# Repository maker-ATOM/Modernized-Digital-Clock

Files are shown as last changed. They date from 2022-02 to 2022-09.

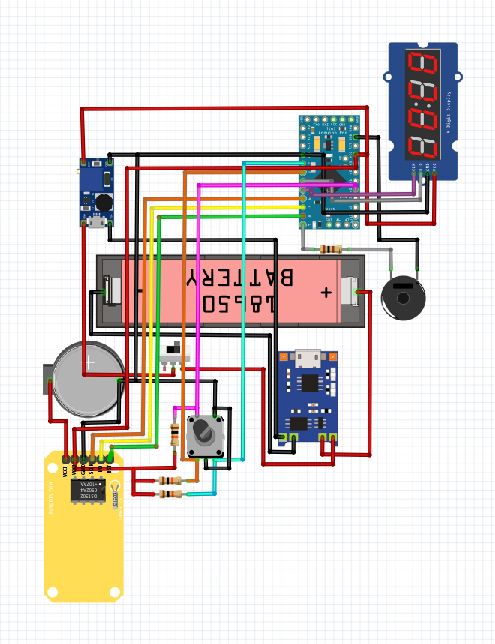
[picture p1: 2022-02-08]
Schematics/fritzing_schematic.jpg

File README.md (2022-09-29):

# Modernized-Digital-Clock
Build Instructions: https://www.instructables.com/Modernized-Digital-Clock/



### Rendered Image

FAG5CKHKYLK3PZ0

### Exploded view

exploded

Usage Guide of the clock: https://youtu.be/vWBFiRBEp3g

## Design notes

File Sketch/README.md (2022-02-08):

Arduino programs files to program the clock.

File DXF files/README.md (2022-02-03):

DXF file to laser cut the acrylic sheet.
Acrylic sheet 3mm thick clear black. Allows only limited light to pass thorugh without dispersing the light and retains the shape of object.

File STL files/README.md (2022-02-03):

STL files to 3D print.
3D printed in PLA GREY with 0.4mm nozzle, 0.2mm layer height and 100% infill.

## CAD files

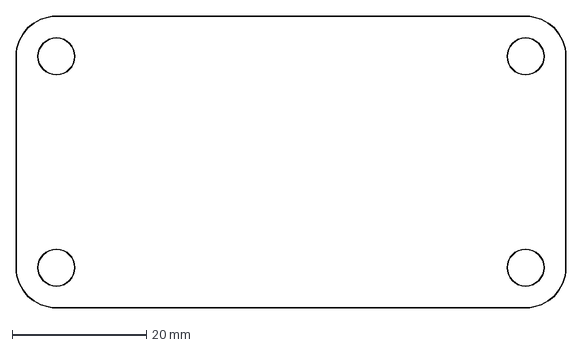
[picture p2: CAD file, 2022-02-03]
DXF files/face plate.dxf
82.0 x 43.5 mm

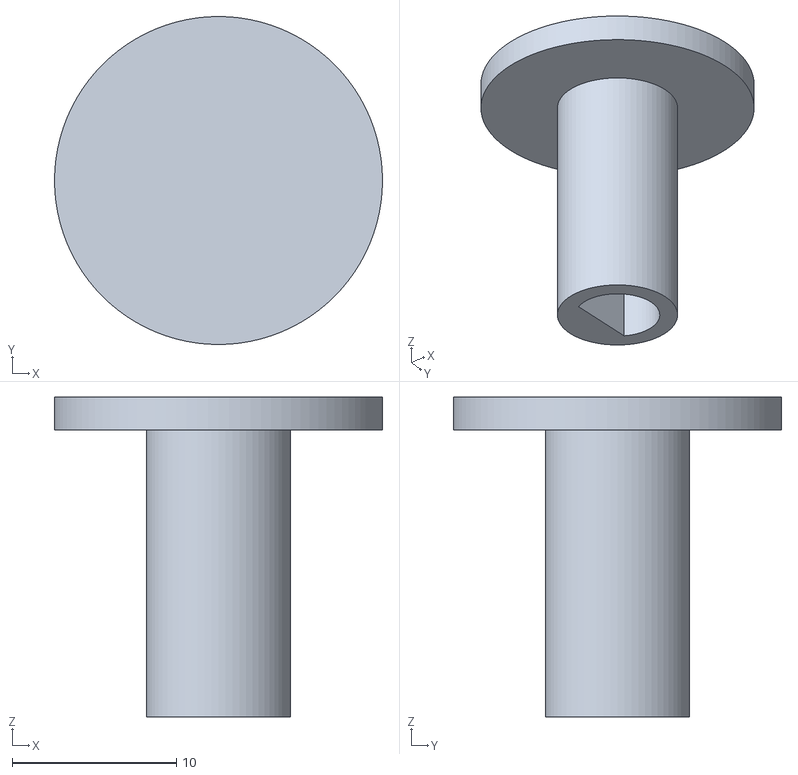
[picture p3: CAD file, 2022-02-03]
STL files/knob.stl
20.0 x 20.0 x 19.5

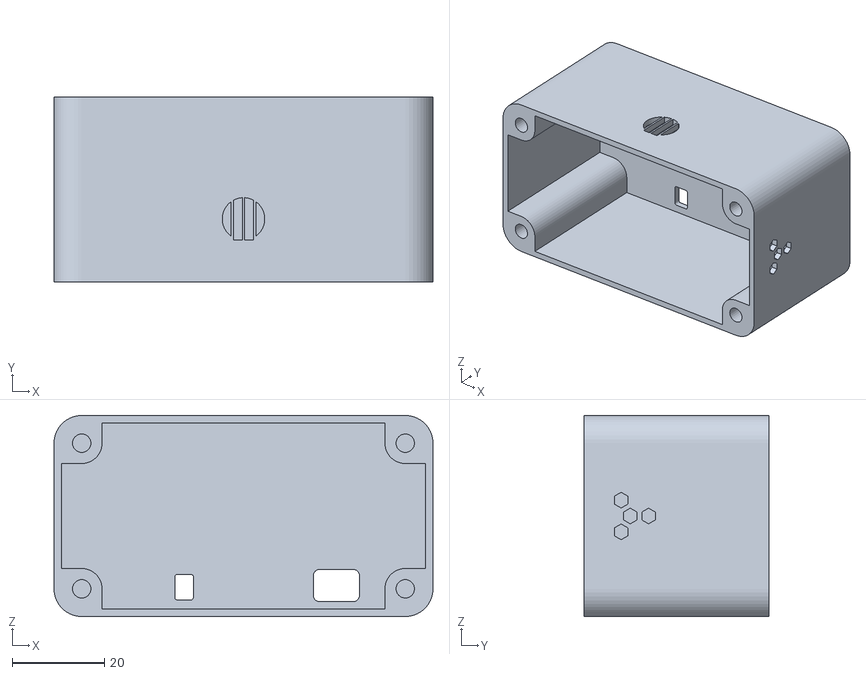
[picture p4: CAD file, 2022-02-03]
STL files/body.stl
82.0 x 40.0 x 43.5

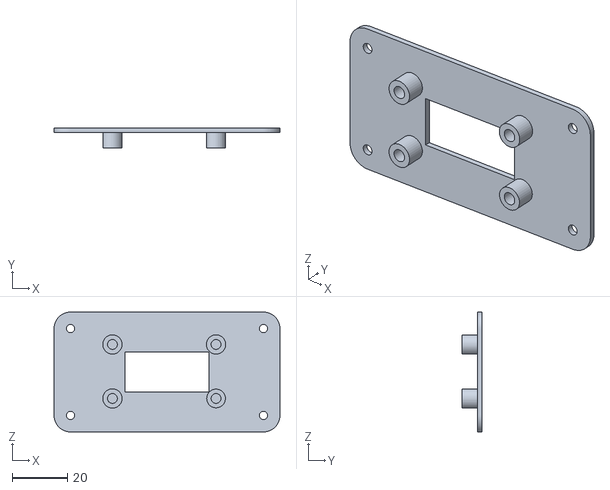
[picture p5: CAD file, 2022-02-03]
STL files/back plate.stl
82.0 x 7.20 x 43.5

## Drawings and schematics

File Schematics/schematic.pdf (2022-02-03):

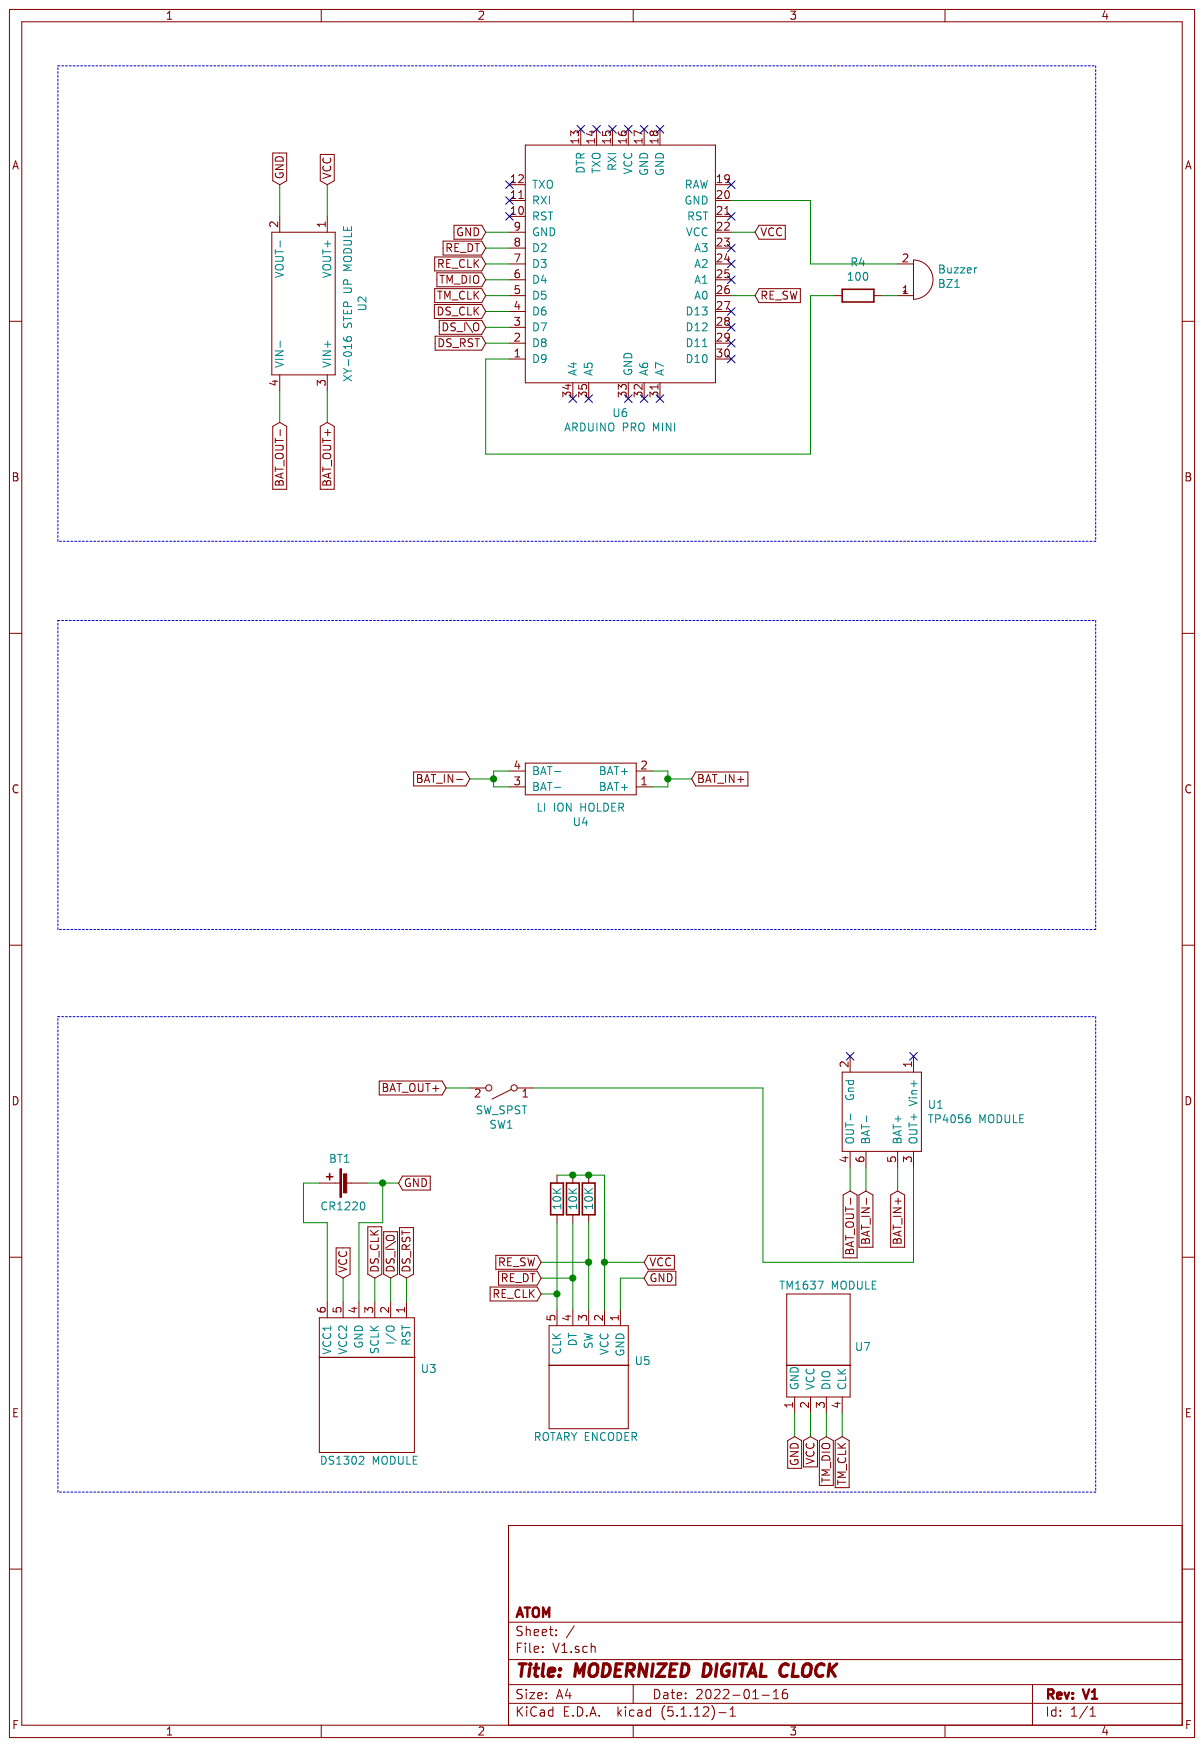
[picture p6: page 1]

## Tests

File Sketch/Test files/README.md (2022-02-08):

These programs are for debugging particularly to check which module is not working properly if any.

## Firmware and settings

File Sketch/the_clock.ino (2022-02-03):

//libraries
#include <TM1637Display.h>
#include <DS1302.h>

//macros
#define TM_CLK 5
#define TM_DIO 4

#define RE_CLK 3
#define RE_DT 2

#define RTC_CLK 6
#define RTC_DIO 7
#define RTC_CE 8

#define buzzer 9

//varibles
volatile byte nowRE_DT = 1;
volatile byte prevRE_DT = 1;

volatile byte button = 0;
byte buttonPressed = false;

volatile byte counter = 0;
byte prevcounter = 0;

byte td1 = 0, td2 = 0, td3 = 0, td4 = 0;
byte ad1 = 0, ad2 = 0, ad3 = 0, ad4 = 0;

byte digichange = 0;
int gettime = 0;

byte brightness = 4;

int setalarm = 0;
byte alarmFlag = false;

//array to display words
uint8_t full[] = {0xff, 0x0ff, 0xff, 0xff};
uint8_t blank[] = {0x00, 0x00, 0x00, 0x00};
uint8_t bright[] = {0x7c, 0xd0, 0x6f, 0x31};
uint8_t set[] = {0x6d, 0x79, 0x31, 0x00};
uint8_t timearr[] = {0x31, 0x30, 0x52, 0x79};
uint8_t dipy[] = {0x5e, 0x30, 0x73, 0x66};
uint8_t alarm[] = {0x77, 0x38, 0x50, 0x52};
uint8_t on[] = {0x00, 0x3f, 0x54, 0x00};
uint8_t off[] = {0x3f, 0x71, 0x71, 0x00};

TM1637Display display = TM1637Display(TM_CLK, TM_DIO);

DS1302 rtc(RTC_CE, RTC_DIO, RTC_CLK);

Time t;

//---------------------------------------------------------------------------------//

void setup()
{
  //register maipulation to set pin change interrupt on A0 pin
  PCICR |= B00000010;
  PCMSK1 |= B00000001;

  pinMode(RE_CLK, INPUT);
  pinMode(RE_DT, INPUT);

  //set the pin to high impedance so humming is inherted
  pinMode(buzzer, INPUT);

  attachInterrupt(digitalPinToInterrupt(2), updateEncoder, CHANGE);
  attachInterrupt(digitalPinToInterrupt(3), updateEncoder, CHANGE);

  display.setBrightness(brightness);

  rtc.halt(false);
  rtc.writeProtect(false);
}

//---------------------------------------------------------------------------------//

void loop()
{

  switch (button)
  {

    case 1: //show time
      display.setSegments(dipy);
      delay(1500);
      display.setSegments(timearr);
      delay(1500);
      while (!buttonPressed)
      {
        t = rtc.getTime();
        gettime = t.min;
        gettime = gettime + (t.hour * 100);
        display.showNumberDecEx(gettime, B01000000, true, 4, 0);

        if ((setalarm == gettime) && (alarmFlag))
        {
          prevcounter = counter;
          while (prevcounter == counter)
          {
            alarmSound();
          }
          alarmFlag = false;
          buttonPressed = false;
        }
        delay(2000);
      }
      break;



    case 2: //change time
      beep();
      display.setSegments(set);
      delay(1500);
      display.setSegments(timearr);
      delay(1500);
      while (!buttonPressed)
      {
        buttonPressed = false;
        if (counter != prevcounter)
        {
          display.setSegments(blank);
          if (counter > prevcounter)
          {
            digichange = (digichange + 1) % 4;
          }
          else
          {
            switch (digichange)
            {
              case 0:
                td4 = (td4 + 1) % 10;
                break;
              case 1:
                td3 = (td3 + 1) % 10;
                break;
              case 2:
                td2 = (td2 + 1) % 10;
                break;
              case 3:
                td1 = (td1 + 1) % 10;
                break;
            }
            rtc.setTime(td4 * 10 + td3, td2 * 10 + td1, 00);
          }
          switch (digichange)
          {
            case 0:
              display.showNumberDec(td4, false, 1, 0);
              break;
            case 1:
              display.showNumberDec(td3, false, 1, 1);
              break;
            case 2:
              display.showNumberDec(td2, false, 1, 2);
              break;
            case 3:
              display.showNumberDec(td1, false, 1, 3);
              break;
          }
          beep();
          prevcounter = counter;
        }
        delay(5);
      }
      break;

    case 3: //change brightness
      beep();
      display.setSegments(set);
      delay(1500);
      display.setSegments(bright);
      delay(1500);
      while (!buttonPressed)
      {
        buttonPressed = false;
        display.setSegments(full);
        if (counter != prevcounter)
        {
          if (brightness > 7)
          {
            brightness = 0;
          }
          brightness++;
          display.setBrightness(brightness);
          prevcounter = counter;
          beep();
        }
        delay(5);
      }
      break;

    case 4: //set alarm
      beep();
      display.setSegments(set);
      delay(1500);
      display.setSegments(alarm);
      delay(1500);
      while (!buttonPressed)
      {

        if (counter != prevcounter)
        {

          alarmFlag = !alarmFlag;
          if (alarmFlag)
          {
            display.setSegments(on);
            beep();
            delay(2000);
            while (!buttonPressed)
            {
              if (counter != prevcounter)
              {
                beep();
                display.setSegments(blank);
                if (counter > prevcounter)
                {
                  digichange = (digichange + 1) % 4;
                }
                else
                {
                  switch (digichange)
                  {
                    case 0:
                      ad4 = (ad4 + 1) % 10;
                      break;
                    case 1:
                      ad3 = (ad3 + 1) % 10;
                      break;
                    case 2:
                      ad2 = (ad2 + 1) % 10;
                      break;
                    case 3:
                      ad1 = (ad1 + 1) % 10;
                      break;
                  }
                  setalarm = (ad4 * 1000) + (ad3 * 100) + (ad2 * 10) + ad1;
                }
                switch (digichange)
                {
                  case 0:
                    display.showNumberDec(ad4, false, 1, 0);
                    break;
                  case 1:
                    display.showNumberDec(ad3, false, 1, 1);
                    break;
                  case 2:
                    display.showNumberDec(ad2, false, 1, 2);
                    break;
                  case 3:
                    display.showNumberDec(ad1, false, 1, 3);
                    break;
                }

                prevcounter = counter;
              }
              delay(5);
            }

          }
          else
          {
            display.setSegments(off);
          }
          prevcounter = counter;
          beep();
        }
        delay(5);
      }
      break;
    default:
      button = 1;
  }

  buttonPressed = false;

}

//---------------------------------------------------------------------------------//

ISR (PCINT1_vect)
{
  if (!digitalRead(A0))
  {
    button++;
    buttonPressed = true;
  }
  delay(1);
}

//---------------------------------------------------------------------------------//

void updateEncoder()
{
  nowRE_DT = digitalRead(3);
  if ((nowRE_DT != prevRE_DT) && digitalRead(2))
  {
    if (nowRE_DT)
    {
      counter--;
    }
    else
    {
      counter++;
    }
  }
  prevRE_DT = nowRE_DT;
}

//---------------------------------------------------------------------------------//

void beep()
{
  tone(buzzer, 1500);
  delay(50);
  noTone(buzzer);
  pinMode(buzzer, INPUT);
}

//---------------------------------------------------------------------------------//

void alarmSound()
{
  tone(buzzer , 1000);
  delay(200);
  noTone(buzzer);
  tone(buzzer, 1000);
  delay(200);
  noTone(buzzer);
  delay(1250);
}

//---------------------------------------------------------------------------------//

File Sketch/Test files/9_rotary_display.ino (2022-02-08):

//external interrupts attached to CLK and DT of encoder
//updates a variable based on rotation of enocder
//and displays on TM1637

#include <TM1637Display.h>

#define TM_CLK 5
#define TM_DIO 4

#define RE_CLK 2
#define RE_DT 4
#define RE_SW 3

volatile bool direc = false;
volatile byte nowRE_DT = 1;
volatile byte prevRE_DT = 1;
volatile byte counter = 0;
byte prevcounter = 0;


TM1637Display display = TM1637Display(TM_CLK, TM_DIO);

void setup()
{
  pinMode(RE_CLK, INPUT);
  pinMode(RE_DT, INPUT);
  pinMode(RE_SW, INPUT);


  attachInterrupt(digitalPinToInterrupt(2), updateEncoder, CHANGE);
  attachInterrupt(digitalPinToInterrupt(3), updateEncoder, CHANGE);

  display.setBrightness(0x0a);
}


void loop()
{
  if (counter != prevcounter)
  {
    display.showNumberDecEx(counter, B01000000, true, 4, 0);
    prevcounter = counter;
    prevRE_DT = 1;
  }
}


void updateEncoder()
{
  nowRE_DT = digitalRead(3);
  if ((nowRE_DT != prevRE_DT) && digitalRead(2))
  {
    if (nowRE_DT)
    {
      direc = false;
      counter--;
    }
    else
    {
      direc = true;
      counter++;
    }
  }
  prevRE_DT = nowRE_DT;
}
